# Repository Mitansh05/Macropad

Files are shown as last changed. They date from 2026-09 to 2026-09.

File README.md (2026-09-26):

# My Macropad

This is my open source 9-key macropad, this project is mainly built around the **Seeed Studio XIAO RP2040**, but I have also provided some files that will help you if you want to use the **Micro Pico**.

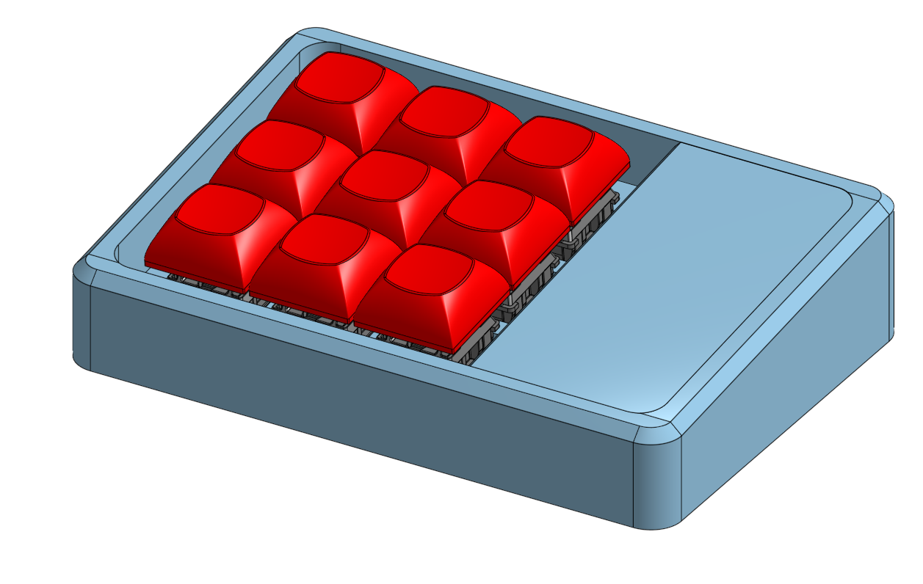
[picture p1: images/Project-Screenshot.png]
Hero-Pic


## Author

- [@Mitansh05](https://github.com/Mitansh05)

## PCB

### Try it yourself



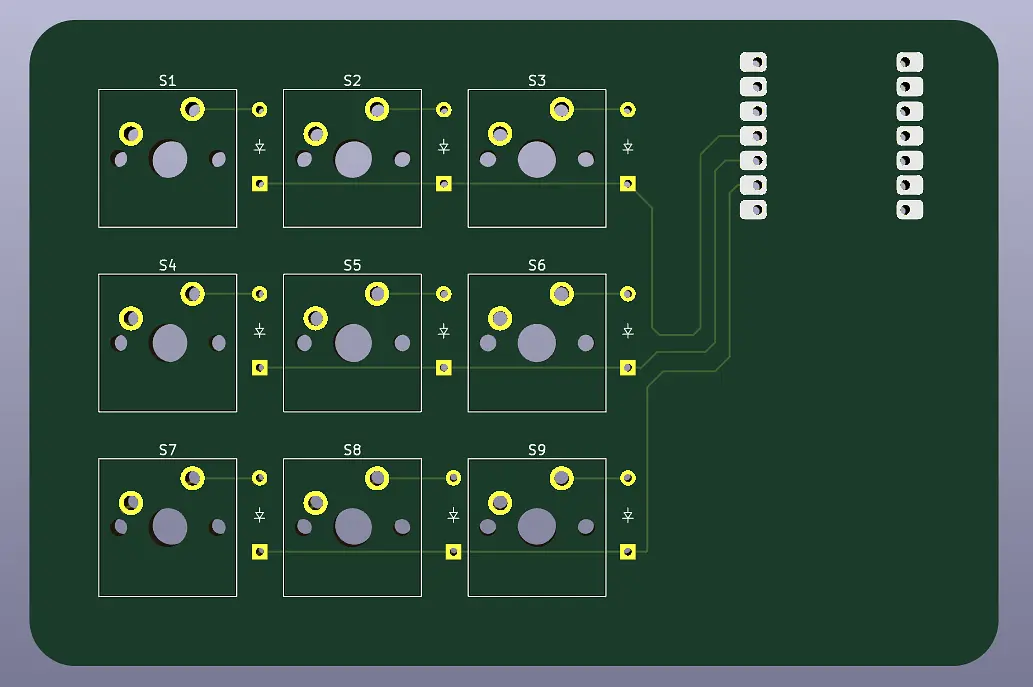
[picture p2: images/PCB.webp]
PCB Image


### Schematic / PCB imgs

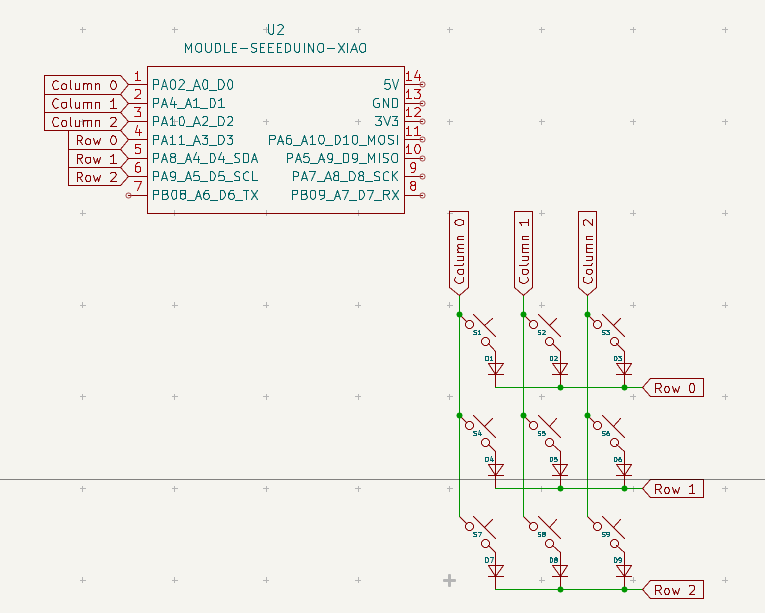
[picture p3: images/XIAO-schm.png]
Project schematic

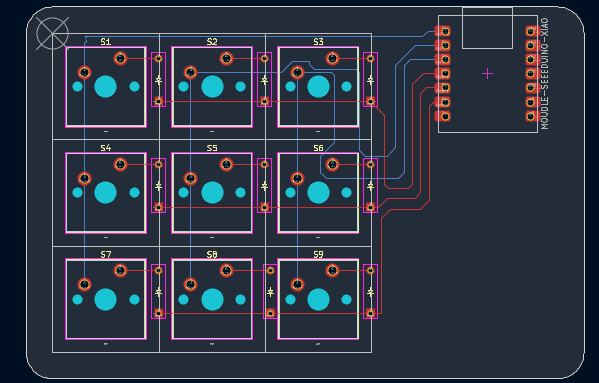
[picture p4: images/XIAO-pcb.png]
Project PCB


#### Alt approch to the PCB:

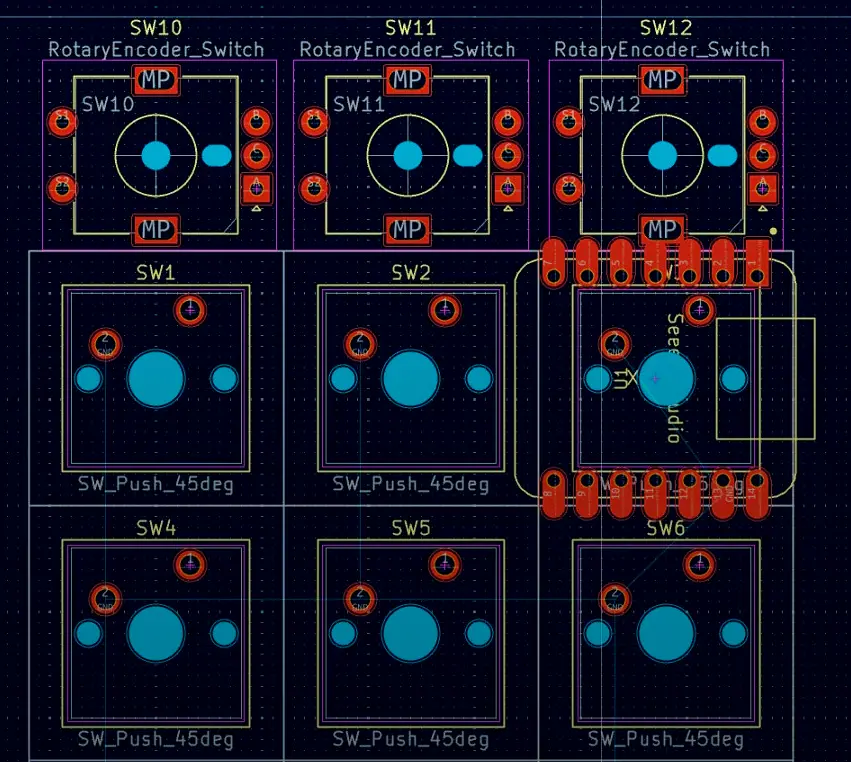
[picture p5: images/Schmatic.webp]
Project Screenshot - Pico


## Getting Started - Firmware / setup

- Step 1: Install **CircuitPython**.
- Step 2: Hold down the physical **`BOOT`** / **`BOOTSEL`** button on your Seeed XIAO board.
- Step 3: Drag and drop all of the files inside `Firmware` folder (`kmk`, `boot.py`, `code.py`, `keymap.py`) into the **CIRCUITPY** inside the XIAO.
- Step 4: Safely eject the drive from your decvice, physically unplug the USB cable from the XIAO for ~3sec and then plug it back in to make sure the macros are initialized.

### Active Layout Blueprint

This is the 9 key layout that is pre-loaded on the macropad.

| Left Column | Center Column | Right Column |
| :--- | :--- | :--- |
| **📑 Copy**<br>`Pin D0` | **📋 Paste**<br>`Pin D1` | **📊 Calculator**<br>`Pin D2`  |
| **🎵 Play / Pause**<br>`Pin D3` | **⏮️ Prev Track**<br>`Pin D4` | **🔇 Panic Mute**<br>`Pin D5`  |
| **🛠️ Task Manager**<br>`Pin D6` | **✂️ Snipping Tool**<br>`Pin D7` | **🔒 Lock Screen**<br>`Pin D8` |

## Resources Used

[HackClub HackPad](https://hackpad.hackclub.com/guide)

[KiCad](https://www.kicad.org/)

### Additional info

- Docunmentation can be found on [HackClub](https://stardance.hackclub.com/projects/44402)

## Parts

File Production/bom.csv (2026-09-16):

Designator | Footprint | Quantity | Value | LCSC Part #
D1, D2, D3, D4, D5, D6, D7, D8, D9 | Diode_DO-35 | 9 | ~
S1, S2, S3, S4, S5, S6, S7, S8, S9 | MX_PCB_1.00u | 9 | ~
U2 | Seeed_XIAO_RP2040 | 1 | MOUDLE-SEEEDUINO-XIAO

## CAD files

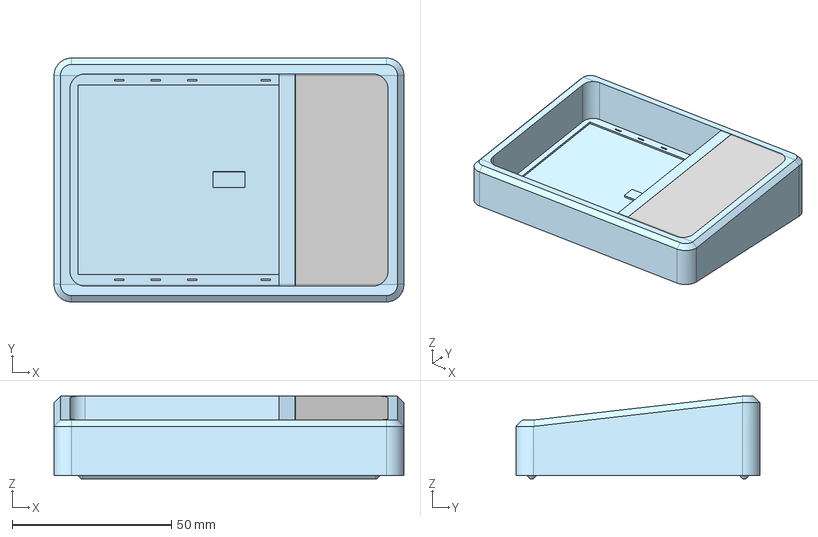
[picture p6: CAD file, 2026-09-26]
CAD-Files-4-Printing/Print-Case-Assembled.step
110.0 x 76.7 x 26.0 mm

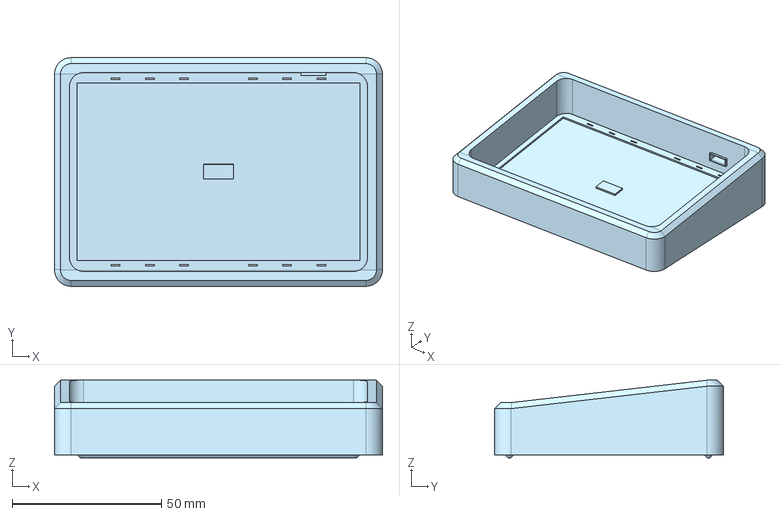
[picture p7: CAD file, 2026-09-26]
CAD-Files-4-Printing/Print-Main-Case-Structure.step
110.0 x 76.7 x 26.0 mm

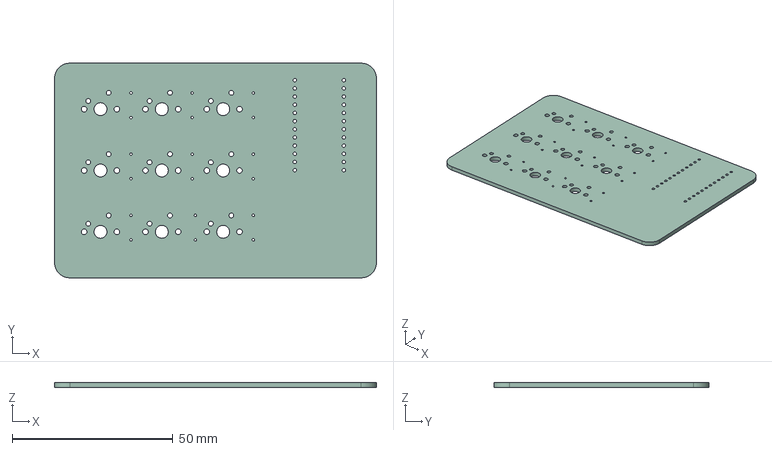
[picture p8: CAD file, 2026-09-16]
PCB/Macropad.step
100.0 x 66.7 x 1.51 mm

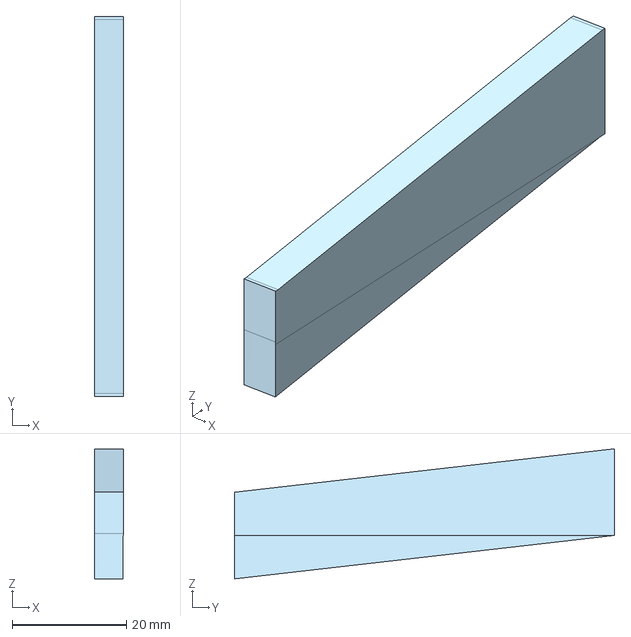
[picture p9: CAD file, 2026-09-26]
CAD-Files-4-Printing/Print-Case-Divider.step
5.00 x 66.6 x 22.7 mm

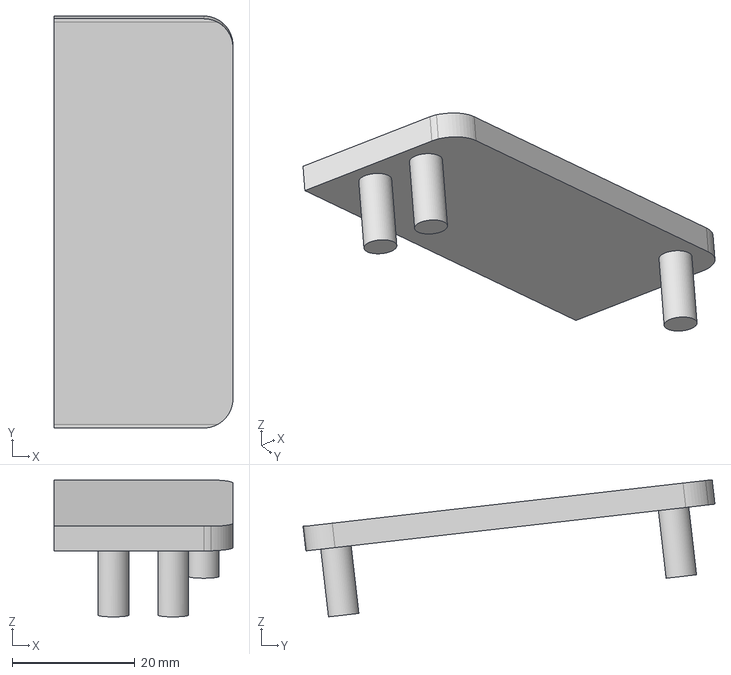
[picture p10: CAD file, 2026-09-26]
CAD-Files-4-Printing/Print-Case-Controller-Cover-Optional.step
29.2 x 67.1 x 22.3 mm

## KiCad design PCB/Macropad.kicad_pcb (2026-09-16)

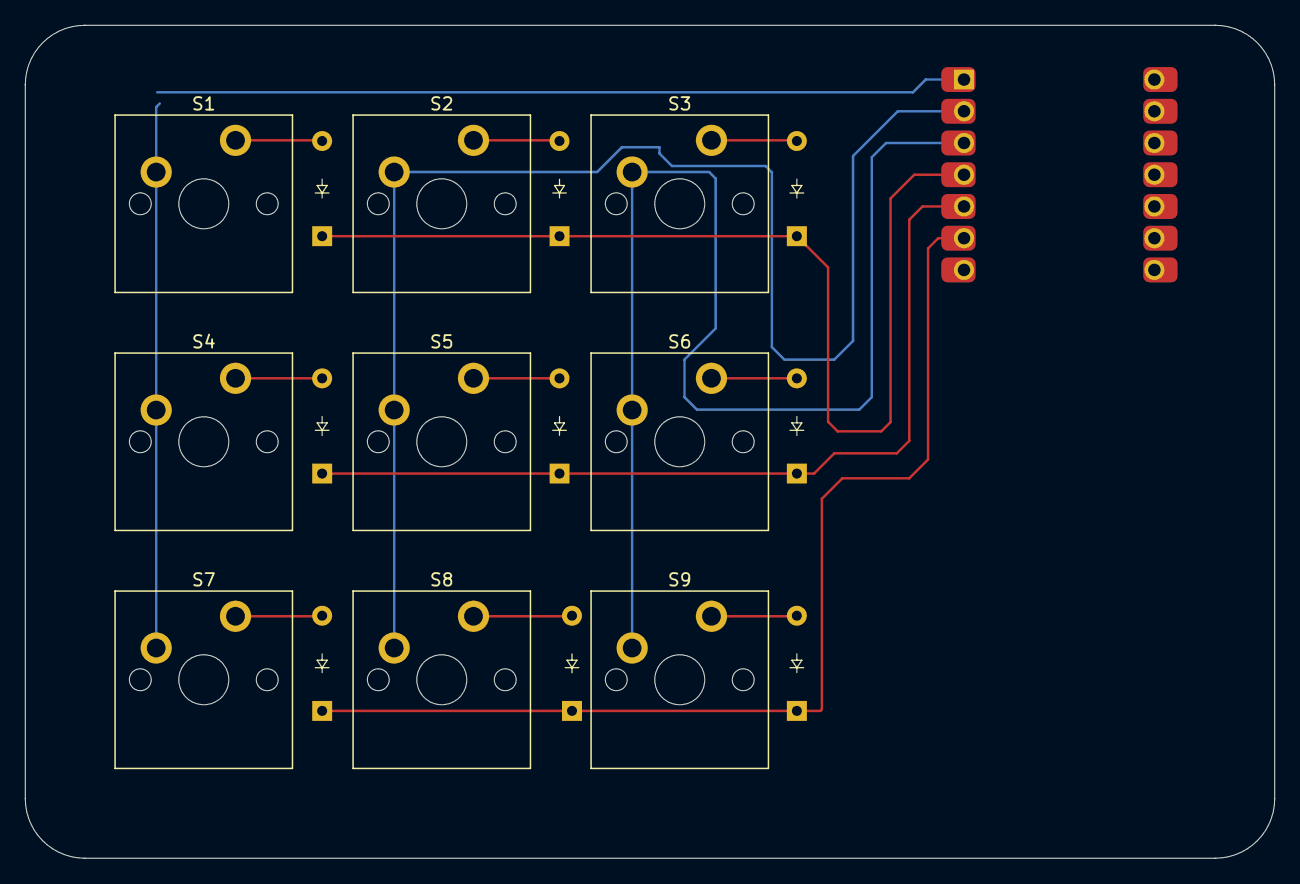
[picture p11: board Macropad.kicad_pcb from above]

Board: 2 copper layers, 100.0 x 66.7 mm, 19 parts (0 on the bottom side), 15 nets.

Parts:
D1, D2, D3, D4, D5, D6, D7, D8, D9: Diode_DO-35
S1, S2, S3, S4, S5, S6, S7, S8, S9: MX_PCB_1.00u
U2: MOUDLE-SEEEDUINO-XIAO; Seeed_XIAO_RP2040

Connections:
Column 0: S1.1, S4.1, S7.1, U2.1 (PA02_A0_D0)
Column 1: S2.1, S5.1, S8.1, U2.2 (PA4_A1_D1)
Column 2: S3.1, S6.1, S9.1, U2.3 (PA10_A2_D2)
unnamed: D1.2 (A), S1.2
unnamed: D2.2 (A), S2.2
unnamed: D3.2 (A), S3.2
unnamed: D4.2 (A), S4.2
unnamed: D5.2 (A), S5.2
unnamed: D6.2 (A), S6.2
unnamed: D7.2 (A), S7.2
unnamed: D8.2 (A), S8.2
unnamed: D9.2 (A), S9.2
Row 0: D1.1 (K), D2.1 (K), D3.1 (K), U2.4 (PA11_A3_D3)
Row 1: D4.1 (K), D5.1 (K), D6.1 (K), U2.5 (PA8_A4_D4_SDA)
Row 2: D7.1 (K), D8.1 (K), D9.1 (K), U2.6 (PA9_A5_D5_SCL)

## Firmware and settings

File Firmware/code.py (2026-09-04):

import board
from kmk.kmk_keyboard import KMKKeyboard
from kmk.keys import KC
from kmk.scanners.keypad import KeysScanner

keyboard = KMKKeyboard()

keyboard.matrix = KeysScanner(
    pins = [
        board.D0, board.D1, board.D2,
        board.D3, board.D4, board.D5,
        board.D6, board.D7, board.D8
    ],
    value_when_pressed = False
)

keyboard.keymap = [
    [
        KC.LCTRL(KC.C), KC.LCTRL(KC.V), KC.CALCULATOR,
        KC.MPLY, KC.MPRV, KC.MUTE,
        KC.LCTRL(KC.LSFT(KC.ESC)), KC.LWIN(KC.LSFT(KC.S)), KC.LWIN(KC.L)
    ]
]

if __name__ == "__main__":
    keyboard.go()

    

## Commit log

2026-08-07 Revise parts list and include CAD information
    Updated parts list and added CAD section with link.
2026-09-04 Add KMK firmware for XIAO 3x3 macropad
    Initial import of a KMK-based CircuitPython firmware for a diodeless 3x3 Seeed XIAO macropad. Adds top-level files (README, boot.py, code.py, keymap.py, keyboard.json) and a bundled kmk package provi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
    Highlights:
    - boot.py configures USB HID devices and sets device name.
    - code.py configures KeysScanner on D0..D8 and a default single-layer keymap (clipboard, media, system keys) and starts keyboard.go().
    - README documents wiring and de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
2026-09-08 Update README and add PCB images
    This commit updates the project README to use the new images folder and fixes the screenshot path. It also adds PCB and schematic preview images and documents the alternate compact PCB design in the project documentation.
2026-09-14 Add PCB preview badge to README
    This change adds a KiCanvas badge and link to the README so readers can view the PCB layout directly in the browser from the project repository.
2026-09-14 Add PCB preview badge to README
    Update the project README with a KiCanvas badge linking to the PCB design preview, making the hardware layout easier to inspect directly from GitHub.
2026-09-15 Add PCB docs and firmware guide
    Refresh the README with PCB and schematic media, reorganize the CAD section, and add setup instructions for flashing the CircuitPython firmware. This also documents the active 9-key layout and the as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
2026-09-16 Added the production folder form KiCad
    [Macropad.kicad_pcb, Macropad.kicad_sch, Macropad.step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]
2026-09-16 Fix PCB preview link in README
    The README’s KiCanvas badge was pointing to a placeholder repository URL. This updates it to the actual PCB file in the project, so the PCB preview link works correctly from the main branch.
2026-09-16 Fix README image paths
    Update the README image URLs to use forward slashes instead of Windows-style backslashes so the PCB and schematic images render correctly on GitHub and other platforms.
2026-09-26 Submission Changes
    Made the changes that were needed for the submission of the project.
    [Macropad.kicad_pcb, Macropad.kicad_sch, Macropad.step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]
2026-10-30 Update bom.csv with new parts and pricing
    Added additional parts with estimated prices and quantities.
2026-10-30 Revise BOM format with part details and pricing
    Updated the BOM CSV to include part descriptions and estimated prices.
